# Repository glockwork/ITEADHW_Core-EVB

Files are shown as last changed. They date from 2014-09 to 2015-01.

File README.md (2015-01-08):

Core-EVB
================

    History:
    V1.4
    Add the auto reset circuit.
    V1.3
    Improve the Mic and speaker circuit.
    Replace HLF-W12 to HLF-W15.
    Add the PWM and Power function in FPC.
    Fix the RJ45 LED bug.
    Fix some stablity issues.
    V1.2
    First release.

================

Core EVB is a customized evaluation board for ITEAD Core AW204x, which pinouts the functional pins of AW204x to the corresponding physical interface such as USB ports, SD card slot Ethernet port etc. Moreover, Core EVB provides a 40 pins interface that is compatible with RPI B+, which will help developers utilize the existing Add-on more easily.

Common A20 development boards in the market only provide Line-in/Line-out interface so that they can't drive a loudspeaker directly. However, we add power amplifier so that it can drive 4ohm or 8ohm speaker easily.

You can get more information about this project on our wiki:
http://wiki.iteadstudio.com/Core_EVB

Copyright © ITEAD Studio

Lcisense: GPL V3

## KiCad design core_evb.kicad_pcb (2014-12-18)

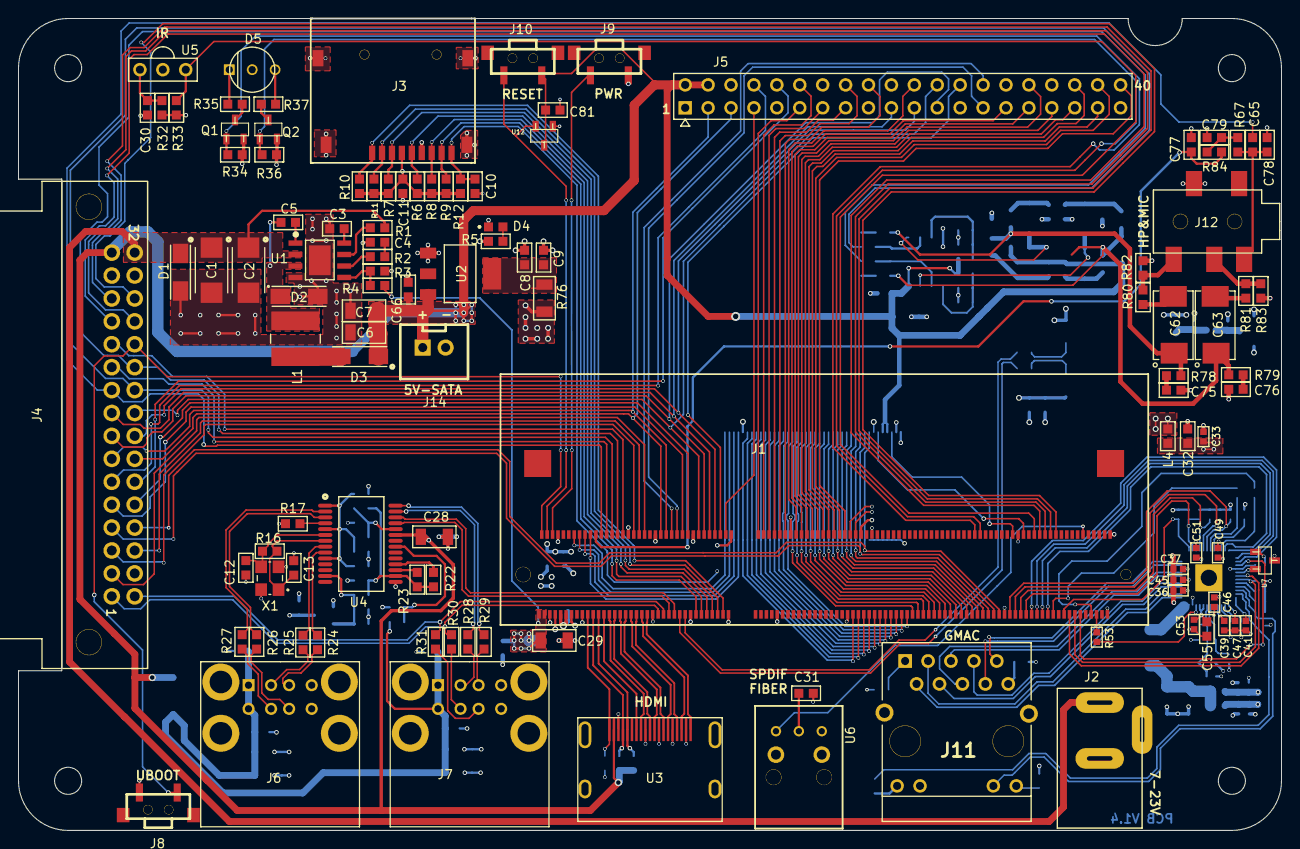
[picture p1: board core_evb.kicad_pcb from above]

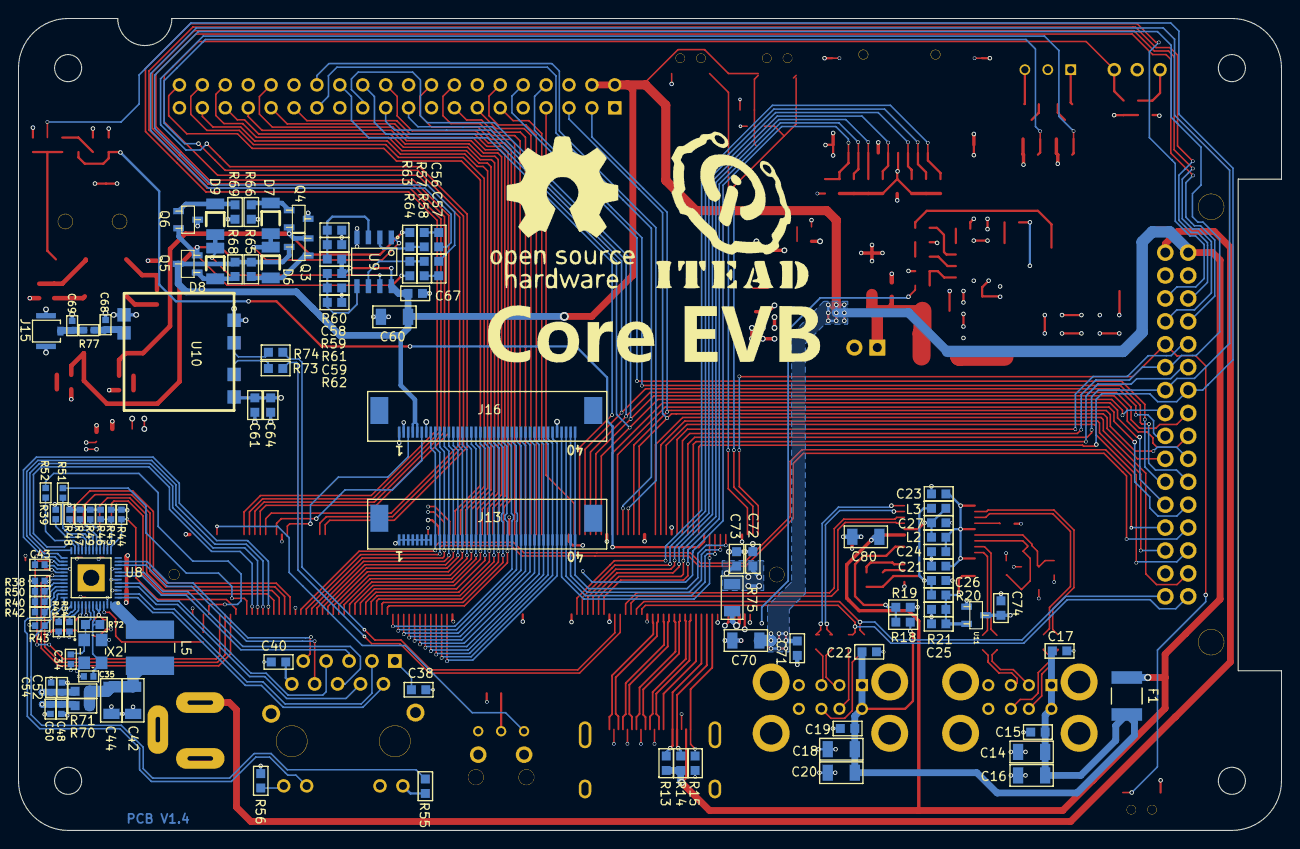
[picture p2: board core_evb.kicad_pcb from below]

Board: 4 copper layers, 140.0 x 90.0 mm, 216 parts (105 on the bottom side), 225 nets.

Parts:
C1, C2: 22uF/C6031-28; CAPMP6032X280
C3, C9, C10, C11, C15, C17, C19, C21, C22, C23, C24, C26, C27, C38, C40, C61, C67, C71, C74, C75, C76, C81: 100nF/0603; STD0603
C4: 3.9nF/0603; STD0603
C5: 10nF/0603; STD0603
C6, C7, C14, C16, C18, C20, C28, C29, C42, C44, C60, C70, C80: 22uF/1206; STD1206
C8, C32, C55, C56, C57, C58, C59, C64, C66, C72, C73, C77, C79: 10uF/0603; STD0603
C12, C13: 12pF/0603; STD0603
C25, C65: 1uF/0603; STD0603
C30, C31: 4.7uF/0603; STD0603
C33, C36, C37, C39, C41, C43, C45, C46, C47, C48, C49, C50, C51, C52, C53, C54: 100nF/0402; STD0402
C34, C35: 22pF/0402; STD0402
C62, C63: 470uF/E7343-43; CAPMP7343X430
C68, C69: NC/0402; STD0402
C78: NC/10pF/0603; STD0603
D1, D2, D3: 1N5819; DIOM5025X231
D4: GREEN/0603; LED0603
D5: 3PLED
D6, D7, D8, D9: 1N4148; diomelf3517
F1: 500mA/1812; STD1812
J1: DIMM204; TYCO-2-2013022
J2: DC_SOCKET
J3: MICRO-SD-TF01
J4: CON-16X2; 9001-35321C00A
J5: CON_2X20; ZCZ254-2X20
J6, J7: USB_B_F_X2
J8, J9, J10: S_1P1T; TS-017
J11: RJ45-HR911130C; RJ45-HY911130C
J12: PJ-327F
J13, J16: CON_1X40; fpc40_0_5mm_up
J14: CON-1X2; XH254-2P
J15: IPX; ipx
L1: 10uH/5.2X5.2/3A; INDC5252X450N
L2, L3, L4: 100R/100MHZ/0603; STD0603
L5: 4.7uH/5.2X5.2; INDC5252X450N
Q1, Q2: 2N7002; sot_23
Q3, Q5: SI2302; sot_23
Q4, Q6: SI2301; sot_23
R1, R63, R64: 100KR/0603; STD0603
R2: 6.8KR/0603; STD0603
R3, R6, R7, R8, R9, R10, R11, R12, R13, R14, R15, R18, R19, R20, R22, R23, R33, R59, R60, R61, R62, R65, R66, R68, R69, R82, R83: 10KR/0603; STD0603
R4: 44.2KR/0603; STD0603
R5, R34, R35, R36, R37: 1KR/0603; STD0603
R16, R72: 1MR/0603; STD0603
R17: 680R/0603; STD0603
R21: NC/10KR/0603; STD0603
R24, R25, R26, R27, R28, R29, R30, R31, R73, R74, R78, R79: 22R/0603; STD0603
R32, R84: 100R/0603; STD0603
R38: 1.5KR/0402; STD0402
R39, R40, R42, R43, R44, R46, R47, R48, R49, R50: 4.7KR/0402; STD0402
R41, R51, R52, R53, R77: 0R/0402; STD0402
R45: NC/4.7KR/0402; STD0402
R54: 2.49KR/0402; STD0402
R55, R56: 510R/0603; STD0603
R57, R58: 20KR/0603; STD0603
R67: 2KR/0603; STD0603
R70, R71, R80, R81: 0R/0603; STD0603
R75: 0R/1206; STD1206
R76: NC/0R/1206; STD1206
U1: MP2307; SOP127P600X150-8T330X240
U2: LM1117; SOT-223
U3: HDMI; hdmi-001-05
U4: GL850G; SSOP-28
U5: HS0038B
U6: HLT1160
U7, U11: APX809; sot_23
U8: RTL8211E; QFN40P600X600X80-49P
U9: SGM358; SOP8
U10: HLF-W12
U12: APX810; sot_23
X1: 12MHz; OSCCC250X320X100
X2: 25MHz; OSCCC250X320X100

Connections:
3V3: C11.1, C31.1, C61.1, C64.1, C72.1, C73.1, C74.1, D5.2, J3.4, J4.30, J5.1, J5.17, L4.1, R5.1, R6.1, R7.1, R8.1, R9.1, R10.1, R11.1, R12.1, R32.2, R33.2, R56.2, R75.1, R76.2, U6.2, U10.1, U11.3
5V: C6.1, C7.1, C28.1, C29.1, C60.1, C66.1, C67.1, C70.1, C71.1, C80.1, C81.1, D3.C, F1.1, J1.1, J1.3, J4.31, J5.2, J5.4, J10.1, J14.1, J16.4, J16.5, Q3.3, Q5.3, R4.2, R13.1, R14.1, R59.1, R61.1, R65.1, R68.1, U2.3, U3.18, U4.23, U9.8, U12.3
/gmac/25MI: C34.1, R72.2, U8.42, X2.1
/gmac/25MO: C35.1, R72.1, U8.43, X2.3
/gmac/ENSWREG: R41.1, U8.38
/gmac/INT#: R39.1, U8.20
/gmac/LED0: J11.13, R42.1, U8.34
/gmac/LED1: R43.1, R55.1, U8.35
/gmac/LED2: R50.1, U8.32
/gmac/PHYRST#: U7.2, U8.29
/gmac/PMEB: R40.1, U8.33
/gmac/REGOUT: L5.1, U8.48
/speaker&mic/HPLOUT: J12.2, R80.2, R82.1
/speaker&mic/HPROUT: J12.3, R81.2, R83.1
/speaker&mic/MIC: C65.2, C78.2, J12.5, R67.2
/usb/HUBDM1: R28.2, U4.27
/usb/HUBDM2: R26.2, U4.2
/usb/HUBDM3: R24.2, U4.8
/usb/HUBDP1: R29.1, U4.28
/usb/HUBDP2: R27.1, U4.3
/usb/HUBDP3: R25.1, U4.9
/usb/HUBRST#: C25.1, R20.1, R21.2, U4.13, U11.2
/usb/HUBSEL: R23.1, U4.17
/usb/OVCUR: R18.1, R19.2, U4.21
/usb/PGANG: R22.1, U4.18
/usb/USB-AVDD: C21.1, C23.1, C24.1, L2.1, U4.1, U4.5, U4.10
/usb/USB-DVDD: C26.1, L3.1, R20.2, R22.2, R23.2, U4.16
/usb/VBUS: C14.1, C15.1, C16.1, C17.1, C18.1, C19.1, C20.1, C22.1, F1.2, J6.1, J6.5, J7.1, J7.5, R18.2
AVDD10: C36.1, C37.1, C39.1, C48.1, C50.1, R70.2, U8.3, U8.9, U8.40
CLKIN: R53.2, U8.46
DM0: J1.45, J4.1, R30.2
DM1: J1.49, U4.25
DM2: J1.53, R73.2
DP0: J1.47, J4.2, R31.1
DP1: J1.51, U4.26
DP2: J1.55, R74.2
DVDD10: C41.1, C43.1, C52.1, C54.1, R71.2, U8.28, U8.36
EGCLKIN: J1.199, R53.1
EGTXCLK: J1.197, R52.2
EMDC: J1.189, U8.30
EMDIO: J1.191, R38.1, U8.31
ERXCLK: J1.183, R51.2
ERXD0: J1.173, R45.1, R46.1, U8.14
ERXD1: J1.171, R49.1, U8.16
ERXD2: J1.169, R47.1, U8.17
ERXD3: J1.167, R48.1, U8.18
ERXDV: J1.187, R44.1, U8.13
ETXD0: J1.181, U8.23
ETXD1: J1.179, U8.24
ETXD2: J1.177, U8.25
ETXD3: J1.175, U8.26
ETXEN: J1.193, U8.27
GND: C1.2, C2.2, C3.2, C4.2, C6.2, C7.2, C8.2, C9.2, C10.2, C11.2, C12.2, C13.2, C14.2, C15.2, C16.2, C17.2, C18.2, C19.2, C20.2, C21.2, C22.2, C23.2, C24.2, C25.2, C26.2, C27.2, C28.2, C29.2, C30.2, C31.2, C32.2, C33.2, C34.2, C35.2, C36.2, C37.2, C38.2, C39.2, C40.2, C41.2, C42.2, C43.2, C44.2, C45.2, C46.2, C47.2, C48.2, C49.2, C50.2, C51.2, C52.2, C53.2, C54.2, C55.2, C58.2, C59.2, C60.2, C61.2, C64.2, C66.2, C67.2, C68.2, C69.2, C70.2, C71.2, C72.2, C73.2, C74.2, C75.2, C76.2, C77.1, C78.1, C79.1, C80.2, C81.2, D1.A, D2.A, D4.2, J1.5, J1.7, J1.8, J1.13, J1.17, J1.34, J1.43, J1.44, J1.57, J1.58, J1.71, J1.72, J1.81, J1.86, J1.107, J1.112, J1.165, J1.170, J1.203, J1.204, J2.3, J3.6, J3.10, J3.11, J3.12, J3.13, J4.29, J5.6, J5.9, J5.14, J5.20, J5.25, J5.30, J5.34, J5.39, J6.4, J6.8, J6.9, J6.10, J6.11, J6.12, J7.4, J7.8, J7.9, J7.10, J7.11, J7.12, J8.1, J9.1, J11.12, J12.4, J13.1, J13.2, J13.3, J13.4, J13.5, J13.6, J13.7, J13.8, J14.2, J15.2, J16.1, J16.2, J16.7, J16.36, Q1.2, Q2.2, Q4.3, Q6.3, R3.2, R15.2, R17.1, R19.1, R21.1, R34.1, R36.1, R43.2, R44.2, R45.2, R54.2, R60.2, R62.2, R66.2, R69.2, R82.2, R83.2, U1.4, U1.9, U2.1, U3.2, U3.5, U3.8, U3.11, U3.17, U3.20, U3.21, U3.22, U3.23, U4.15, U5.2, U6.1, U7.1, U8.47, U8.49, U9.4, U10.4, U10.5, U11.1, U12.1, X1.2, X1.4, X2.2, X2.4
HCEC: J1.25, U3.13
HCOM: J1.32, J4.23
HHPD: J1.19, R15.1, U3.19
HPL: C56.1, J1.28, J4.20
HPR: C57.1, J1.30, J4.22
HSCL: J1.23, R13.2, U3.15
HSDA: J1.21, R14.2, U3.16
HTX0N: J1.31, U3.9
HTX0P: J1.33, U3.7
HTX1N: J1.35, U3.6
HTX1P: J1.37, U3.4
HTX2N: J1.39, U3.3
HTX2P: J1.41, U3.1
HTXCN: J1.27, U3.12
HTXCP: J1.29, U3.10
I2C1-SCL: J1.46, J4.14, J5.5
I2C1-SDA: J1.48, J4.13, J5.3
I2C2-SCL: J1.50, J5.28
I2C2-SDA: J1.52, J5.27
I2S-BCLK: J1.180, J4.26
I2S-DOUT: J1.184, J4.28
I2S-LRCLK: J1.182, J4.27
I2S-MCLK: J1.178, J4.25
IR0-RX: J1.176, R33.1, U5.1
LCD0_CLK: J1.157, J13.12, J16.11
LCD0_D0: J1.109, J13.36, J16.35
LCD0_D1: J1.111, J13.35, J16.34
LCD0_D2: J1.113, J13.34, J16.33
LCD0_D3: J1.115, J13.33, J16.32
LCD0_D4: J1.117, J13.32, J16.31
LCD0_D5: J1.119, J13.31, J16.30
LCD0_D6: J1.121, J13.30, J16.29
LCD0_D7: J1.123, J13.29, J16.28
LCD0_D8: J1.125, J13.28, J16.27
LCD0_D9: J1.127, J13.27, J16.26
LCD0_D10: J1.129, J13.26, J16.25
LCD0_D11: J1.131, J13.25, J16.24
LCD0_D12: J1.133, J13.24, J16.23
LCD0_D13: J1.135, J13.23, J16.22
LCD0_D14: J1.137, J13.22, J16.21
LCD0_D15: J1.139, J13.21, J16.20
LCD0_D16: J1.141, J13.20, J16.19
LCD0_D17: J1.143, J13.19, J16.18
LCD0_D18: J1.145, J13.18, J16.17
LCD0_D19: J1.147, J13.17, J16.16
LCD0_D20: J1.149, J13.16, J16.15
LCD0_D21: J1.151, J13.15, J16.14
LCD0_D22: J1.153, J13.14, J16.13
LCD0_D23: J1.155, J13.13, J16.12
LCD0_DE: J1.159, J13.11, J16.10
LCD0_HSYNC: J1.161, J4.7, J13.10, J16.9
LCD0_VSYNC: J1.163, J4.8, J13.9, J16.8
LINL: C65.1, J1.24, J4.19
LINR: J1.26, J4.21
MDI0+: J11.2, U8.1
MDI0-: J11.3, U8.2
MDI1+: J11.4, U8.4
MDI1-: J11.7, U8.5
MDI2+: J11.5, U8.7
MDI2-: J11.6, U8.8
MDI3+: J11.8, U8.10
MDI3-: J11.9, U8.11
unnamed: J1.9, J1.11, R75.2
unnamed: R3.1, R4.1, U1.5
unnamed: C3.1, U1.8
unnamed: C5.1, U1.1
unnamed: R2.1, U1.6
unnamed: C5.2, D2.C, L1.1, U1.3
unnamed: R1.2, U1.7
unnamed: C4.1, R2.2
unnamed: D4.1, R5.2
unnamed: C8.1, C9.1, R76.1, U2.4
unnamed: D3.A, L1.2
unnamed: J6.6, R26.1
unnamed: J6.7, R27.2
unnamed: J7.2, R28.1
unnamed: J6.3, R25.2
unnamed: J6.2, R24.1
unnamed: J7.3, R29.2
unnamed: J7.6, R30.1
unnamed: J7.7, R31.2
unnamed: C69.1, J15.1, R77.1
unnamed: C68.1, R77.2, U10.6
unnamed: R74.1, U10.3
unnamed: R73.1, U10.2
unnamed: R17.2, U4.4
unnamed: C12.1, R16.1, U4.6, X1.3
unnamed: C13.1, R16.2, U4.7, X1.1
unnamed: Q1.3, R35.1
unnamed: D5.1, R35.2
unnamed: D5.3, R37.2
unnamed: Q2.3, R37.1
unnamed: C30.1, R32.1, U5.3
unnamed: C42.1, C44.1, L5.2, R70.1, R71.1
unnamed: C38.1, J11.1
unnamed: R54.1, U8.39
unnamed: C40.1, J11.10
unnamed: J11.11, R55.2
unnamed: J11.14, R56.1
unnamed: D8.A, Q5.1, R68.2
unnamed: D9.C, Q6.1, R69.1
unnamed: D8.C, D9.A, U9.7
unnamed: D7.C, Q4.1, R66.1
unnamed: D6.C, D7.A, U9.1
unnamed: C62.2, R80.1
unnamed: C63.2, R81.1
unnamed: C76.1, R79.2
unnamed: C75.1, R78.2
unnamed: C62.1, Q3.2, Q4.2, R63.2, R78.1
unnamed: C79.2, R67.1, R84.2
unnamed: C63.1, Q5.2, Q6.2, R64.2, R79.1
unnamed: D6.A, Q3.1, R65.2
unnamed: C59.1, R61.2, R62.1, U9.5
unnamed: C57.2, R58.1
unnamed: C56.2, R57.1
unnamed: R57.2, R63.1, U9.2
unnamed: C58.1, R59.2, R60.1, U9.3
unnamed: R58.2, R64.1, U9.6
PB2: J1.172, J16.6
PB13: J1.194, U6.3
PB22: J1.54, J4.9
PB23: J1.56, J4.10
PG0: J1.88, J5.22
PG1: J1.90, J5.29
PG2: J1.92, J5.31
PG3: J1.94, J5.32
PG4: J1.96, J5.33
PG5: J1.98, J5.35
PG6: J1.100, J5.36
PG7: J1.102, J5.37
PG8: J1.104, J5.38
PG9: J1.106, J5.40
PG10: J1.108, J4.11, J5.8
PG11: J1.110, J4.12, J5.10
PH1: C10.1, J1.116, J3.9, R12.2
PH20: J1.154, Q1.1, R34.2
PH21: J1.156, Q2.1, R36.2
PH27: J1.168, J16.3
PI10: J1.60, J4.18, J5.24
PI11: J1.62, J4.15, J5.23
PI12: J1.64, J4.17, J5.19
PI13: J1.66, J4.16, J5.21
PI14: J1.68, J5.26
PI15: J1.70, J5.7
PI16: J1.74, J5.11
PI17: J1.76, J5.12
PI18: J1.78, J5.13
PI19: J1.80, J5.15
PI20: J1.82, J5.16
PI21: J1.84, J5.18
PWR: J1.6, J9.2
RESET: J1.4, J10.2, U12.2
RXCLK: R51.1, U8.19
SD0-CLK: J1.63, J3.5, R6.2
SD0-CMD: J1.65, J3.3, R7.2
SD0-D0: J1.61, J3.7, R8.2
SD0-D1: J1.59, J3.8, R9.2
SD0-D2: J1.69, J3.1, R10.2
SD0-D3: J1.67, J3.2, R11.2
TVOUT0: J1.36, J4.5
TVOUT1: J1.38, J4.6
TVOUT2: J1.40, J4.3
TXCLK: R52.1, U8.22
UBOOT: J1.2, J4.24, J8.2
USB3V3: C27.1, L2.2, L3.2, U4.24
VDD33: C32.1, C33.1, C45.1, C46.1, C47.1, C49.1, C51.1, C53.1, C55.1, L4.2, R38.2, R39.2, R40.2, R41.2, R42.2, R46.2, R47.2, R48.2, R49.2, R50.2, U7.3, U8.6, U8.15, U8.21, U8.37, U8.41, U8.44, U8.45
VIN: C1.1, C2.1, D1.C, J2.1, J4.32, R1.1, U1.2
VMIC: C77.2, J1.22, R84.1
X1: J1.14, J13.40, J16.40
X2: J1.16, J13.39, J16.39
Y1: J1.18, J13.38, J16.38
Y2: J1.20, J13.37, J16.37

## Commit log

2014-09-25 1.0
    1.0
    [SD0-BLOCK.sch, core.sch, core_evb - Copy.kicad_pcb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]
2014-12-18 1.4
    Fix some issues
    [SD0-BLOCK.sch, core.sch, core_evb.kicad_pcb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]
